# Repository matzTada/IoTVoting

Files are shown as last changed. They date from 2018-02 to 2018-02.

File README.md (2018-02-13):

# IoTVoting

IoT教育向け投票システム  
ボタンを押した回数に対応してフルカラーLEDの色が変わる．複数ノードから無線通信で色情報を一か所に収集し，視覚化する．色のコントロールを遠隔で行うことも可能．

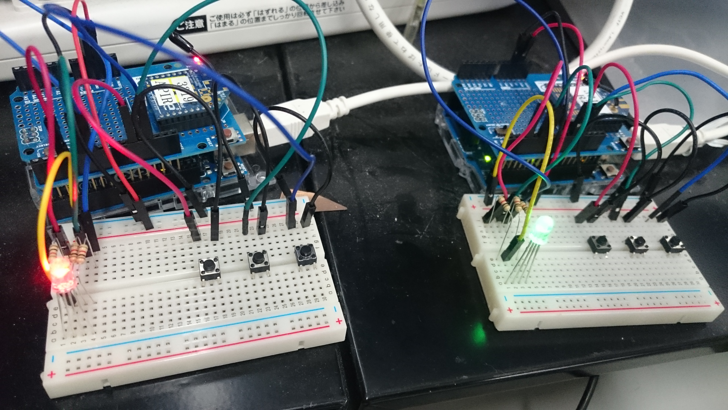
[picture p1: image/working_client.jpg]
working_client

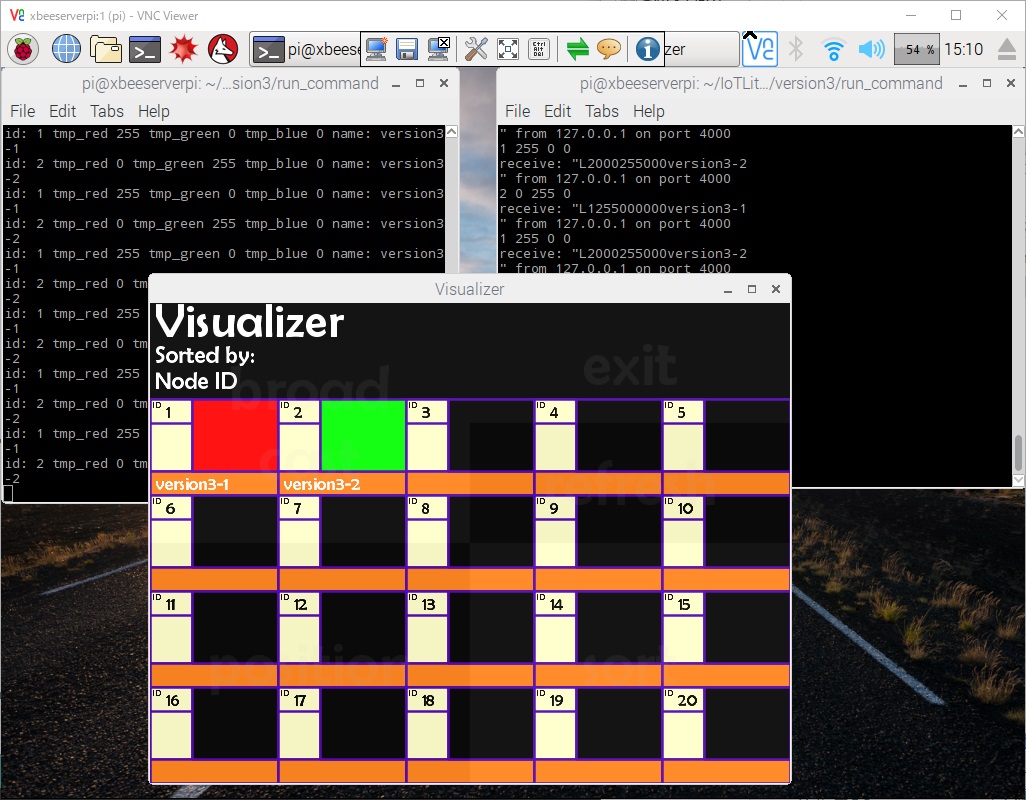
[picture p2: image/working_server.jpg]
working_server


[IoTLiteracyEdu](https://github.com/matzTada/IoTLiteracyEdu)プロジェクトの後継版  
技術面での変更点

* データベースの廃止→プログラム間のソケット通信に変更
* XBee通信のちょっとした改良(WandWoFulも参考に)
* プログラムの簡略化

## やっていること，できること

* クライアント側
	* R,G,Bに対応して一つずつボタンがある
	* ボタンを押した回数に対応してフルカラーLEDの色が変わる
	* LEDの状態（色）を定期的にサーバに送信
* サーバ側
	* クライアント側からのデータを視覚化
	* クライアント側に色情報を一斉送信（コントロールできる）

## 考えられる遊び方

* 一番多い色を集計し，すべてのノードをその色に塗り替える
* 表現できる色それぞれに選択肢を対応付けて投票する
	* 例えば，「お題：好きな果物，選択肢：赤＝リンゴ，緑＝メロン，青＝それ以外」　など
	* 「好きな教科」「好きなスポーツ」「好きな言語」等なんでもできる．
* まわりの人と色を合わせるには
	* プロトコルの考えにもつながる
	* 相談あり，相談なし，事前にルールを決める，隣の人の色しかわからない等の応用が利く
* てかまあ，情報教育としてじゃなくて，単になんかしらの投票するときとか面白いかもね．

## 主要登場人物とつながり

* クライアント側
	* Arduino
	* XBee (ZigBee)
	* Full Color LED (3色LED)
	* Tact switch
* サーバー側
	* Raspberry Pi (別にラズパイじゃなくても可)
	* XBee (ZigBee)
	* Processing
	* Python

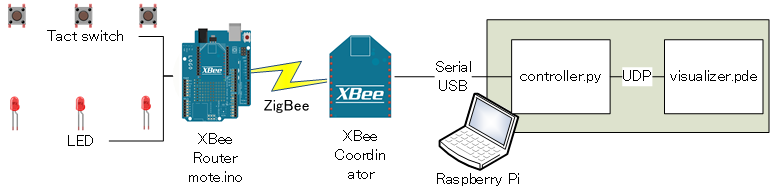
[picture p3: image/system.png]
system
  

## クライアントノード配線

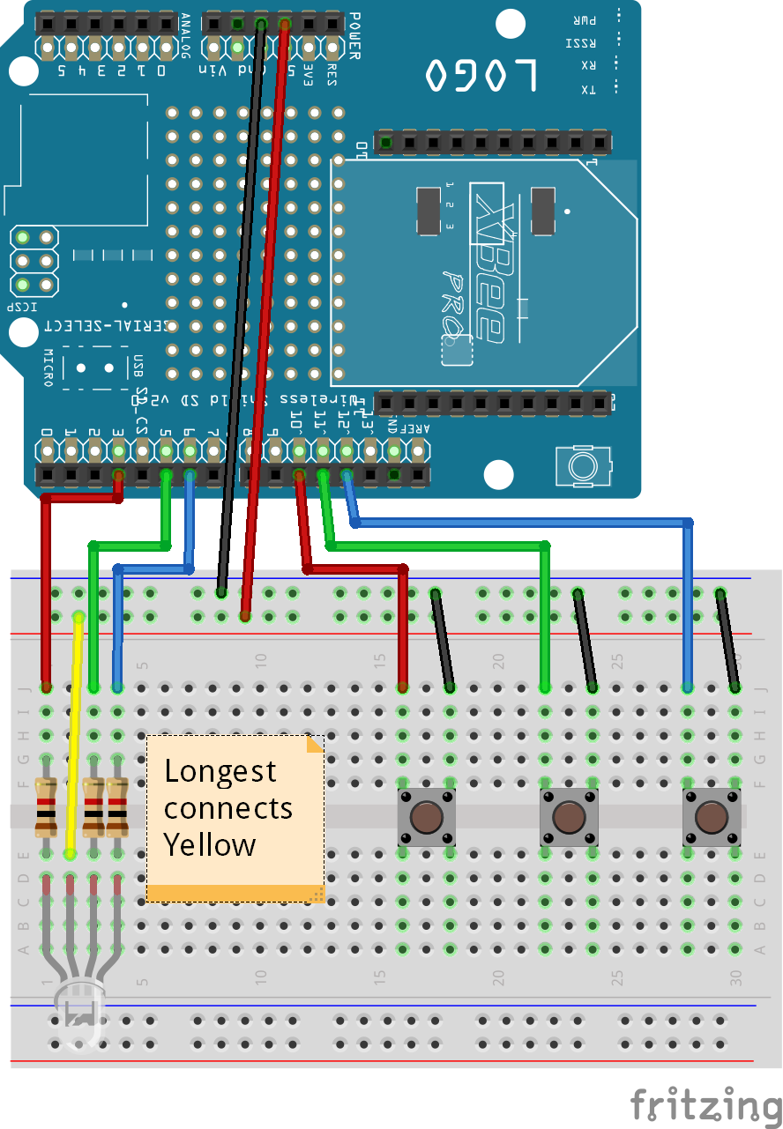
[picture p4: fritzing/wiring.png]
wiring


## 授業に入る前の準備手順

1. Arduinoのノードを配線する
2. ```arduino/mode```以下のプログラムを理解する
3. クライアント側ノードをテストする
	3. ```arduino/mode/mote.inoと同じディレクトリのファイル```をArduino IDEで開き，これをArduinoに焼く
	1. LEDが光るか
	2. ボタンを押してカウントができているか
	3. ボタンを押したらLEDの色が変わるか
2. XBeeの設定
	1. XBeeにテプラなどでIDを貼り、アドレスとの対応をメモっておく
	2. X-CTUのインストール
	3. X-CTUでFirmwareの設定
		1. Coordinatorはネットワークに一つ，他は全部Router
		2. PAN IDをそろえる（そろってないと当たり前のように通信できない）
		3. API enable = 2にする．ライブラリの都合上結構な大事
4. XBeeの通信テスト
	1. 送信はArduinoプログラム（送信先アドレスをCoordinatorに合わせる）
	2. 受信（CoordinatorをPCなりRasPiなりに接続）
		1. X-CTUの端末でみてみる
		3. Pythonで受けてみる（Serialライブラリを使う）
3. ソケット通信テスト
	1. PythonでUDP通信してみる
	2. ProcessingでUDP通信してみる
	3. PythonとProcessingの間でUDP通信してみる
3. サーバ側Controllerのテスト
	1. ```python/controller.py```を試す
	1. クライアント側からデータを受信できているか
	2. 受信したデータをUDPで送信できているか
3. サーバ側Visualizerのテスト
	1. ```processing/visualizer/visualizer.pdeと同じディレクトリのファイル```をProcessing IDEで開く
	2. UDPで受信できているか
	3. 視覚化できているか
4. クライアント側をコントロールできているか試す

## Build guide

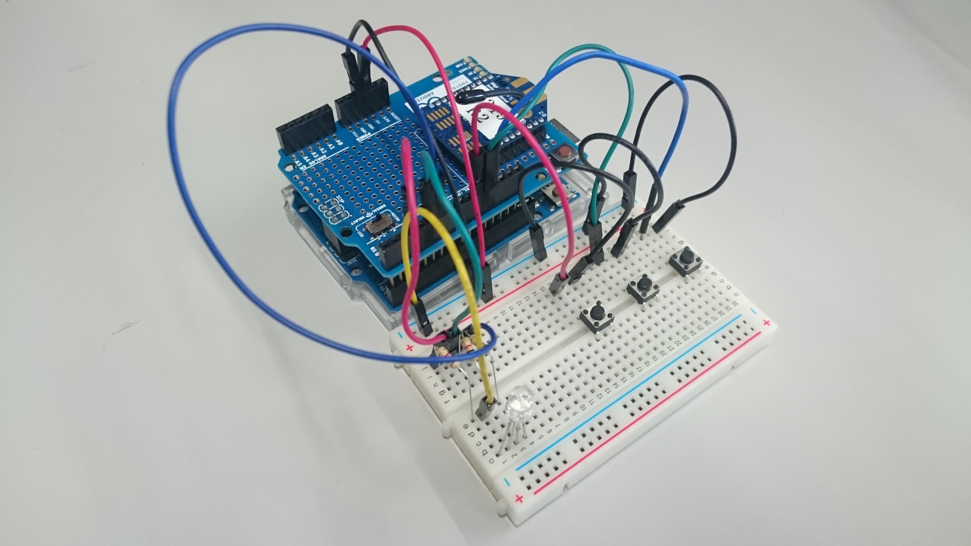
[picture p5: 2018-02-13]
image/wiring_client.jpg

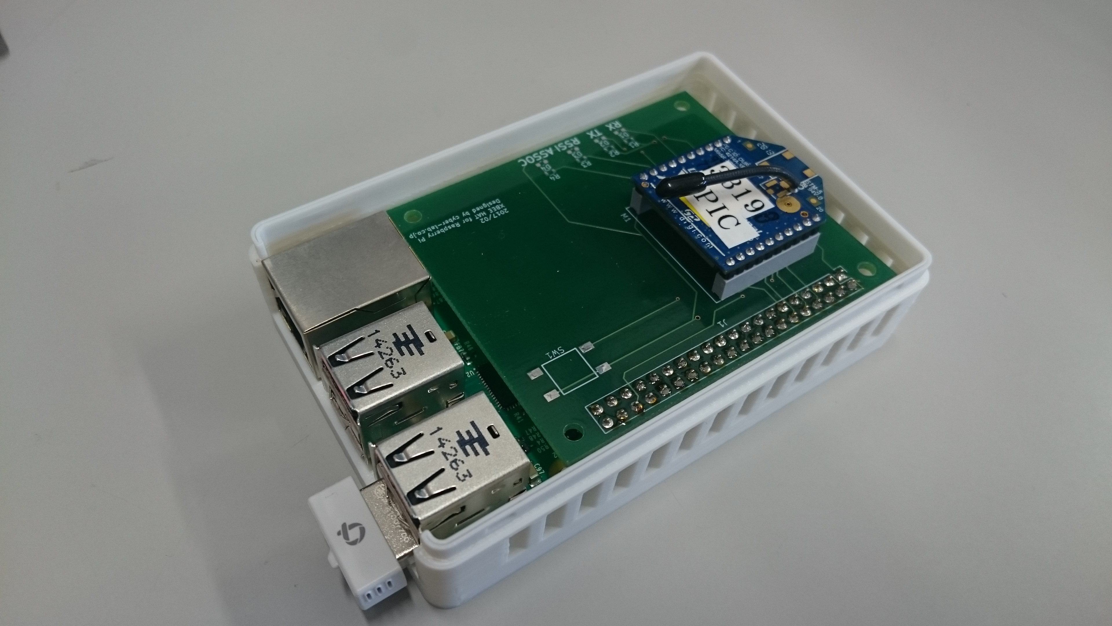
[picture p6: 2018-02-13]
image/wiring_server.jpg

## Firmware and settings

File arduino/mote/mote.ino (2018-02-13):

// mote.ino
// Program for Arduino version3
// Keio University Westlab 2017.12
// Author: Tada Matz

//<==== Please change according to an instruction
String MOTENAME = "version3-2"; //recommended to be between 1 ~ 10
int MOTEID = 2; //should be from 1 ~ 20
//====>Please change according to an instruction

#define LED_RED_PIN 3
#define LED_GREEN_PIN 5
#define LED_BLUE_PIN 6

#define BUTTON_RED_PIN 10
#define BUTTON_GREEN_PIN 11
#define BUTTON_BLUE_PIN 12

int oldR = 0, oldG = 0, oldB = 0; //old button values for click detection
#define CNT_MAX 2
int cntR = 0, cntG = 0, cntB = 0;
int colorR = 0, colorG = 0, colorB = 0;

#include "source.h"
MyXBee myxbee;
unsigned long pastMillis = millis();
#define SEND_INTERVAL 1000
#define LED_HEADER 'L'
#define ID_PACKET_OFFSET '0'

int clickDetection(int _pin, int * _oldstate) { //click detection
  int buttonClicked = 0;
  int newButtonState = digitalRead(_pin);
  if (*_oldstate == HIGH && newButtonState == LOW) buttonClicked = 1; //button pressed. CAUTION pull up
  *_oldstate = newButtonState;
  return buttonClicked;
}

void setup() {
  Serial.begin(9600);
  myxbee.init(Serial);

  pinMode(LED_RED_PIN, OUTPUT);
  pinMode(LED_GREEN_PIN, OUTPUT);
  pinMode(LED_BLUE_PIN, OUTPUT);

  pinMode(BUTTON_RED_PIN, INPUT_PULLUP);
  pinMode(BUTTON_GREEN_PIN, INPUT_PULLUP);
  pinMode(BUTTON_BLUE_PIN, INPUT_PULLUP);
}

void loop() {
  if (clickDetection(BUTTON_RED_PIN, &oldR)) {
    cntR = cntR + 1;
    if (cntR >= CNT_MAX) cntR = 0;
    colorR = (int)map(cntR, 0, CNT_MAX - 1, 0, 255);
  }

  if (clickDetection(BUTTON_GREEN_PIN, &oldG)) {
    cntG = cntG + 1;
    if (cntG >= CNT_MAX) cntG = 0;
    colorG = (int)map(cntG, 0, CNT_MAX - 1, 0, 255);
  }
  if (clickDetection(BUTTON_BLUE_PIN, &oldB)) {
    cntB = cntB + 1;
    if (cntB >= CNT_MAX) cntB = 0;
    colorB = (int)map(cntB, 0, CNT_MAX - 1, 0, 255);
  }

  // receiving
  String receiveStr = myxbee.receiveXBeeData();
  if (receiveStr.length() > 0 && receiveStr.charAt(0) == LED_HEADER) { // packet should be "L1RRRGGGBBB\n"
    // int senderid = int(receiveStr.charAt(1) - ID_PACKET_OFFSET);
    colorR = receiveStr.substring(2, 5).toInt();
    colorG = receiveStr.substring(5, 8).toInt();
    colorB = receiveStr.substring(8, 11).toInt();
  }

  // sending periodically
  if (millis() - pastMillis > SEND_INTERVAL) {
    pastMillis = millis();

    char tempsenddata[1 + 1 + 9];
    sprintf(tempsenddata, "%c%c%03d%03d%03d",
            LED_HEADER,
            MOTEID + int(ID_PACKET_OFFSET),
            colorR, colorG, colorB);
    String data = tempsenddata + MOTENAME + "\n"; // packet should be "L1RRRGGGBBB"
    myxbee.sendXBeeData(data);
  }

  // put on LED
  analogWrite(LED_RED_PIN, 255 - colorR);
  analogWrite(LED_GREEN_PIN, 255 - colorG);
  analogWrite(LED_BLUE_PIN, 255 - colorB);
}

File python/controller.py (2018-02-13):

import serial
import time
import array
import sys

import socket

def readSerial(ser): #can process the Escape mode API = 2
    var = ord(ser.read())
    if(var == 0x7D):
        var = ord(ser.read()) ^ 0x20
    return var

def chrWithEscape(value):
    var = chr(value)
    if(value == 0x7E or value == 0x7D or value == 0x11 or value == 0x13):
        var = chr(0x7D) + chr(value ^ 0x20)
    return var

def makeZigBeeTransmitRequestPacket(dst64addrH, dst64addrL, dst16addr, payLoad): #Frame type = 0x10 packet sender
    length = 1 + 1 + 8 + 2 + 1 + 1 + len(payLoad)

    frameData = chr(0x10) #frameType
    frameData += chr(0x01) #frameID

    sp8 = chr(dst64addrH % 256) #dst64addr High
    dst64addrH = dst64addrH / 256
    sp7 = chr(dst64addrH % 256)
    dst64addrH = dst64addrH / 256
    sp6 = chr(dst64addrH % 256) 
    dst64addrH = dst64addrH / 256
    sp5 = chr(dst64addrH % 256)

    sp12 = chr(dst64addrL % 256) #dst64addr Low
    dst64addrL = dst64addrL / 256
    sp11 = chr(dst64addrL % 256)
    dst64addrL = dst64addrL / 256
    sp10 = chr(dst64addrL % 256)
    dst64addrL = dst64addrL / 256
    sp9 = chr(dst64addrL % 256)

    frameData += sp5 + sp6 + sp7 + sp8 + sp9 + sp10 + sp11 + sp12

    frameData += chr((dst16addr / 256) % 256) #dst16addr
    frameData += chr(dst16addr % 256)

    frameData += chr(0x00) #Broadcast radius
    frameData += chr(0x00) #options

    frameData += payLoad #data payload

    checksum = 0 #checksum calculation
    for i in frameData:
        checksum += ord(i)
    checksum = 0xFF - ord(chr(checksum % 256))
    # print "checksum:", checksum

    tempPacket = chr((length / 256) % 256) + chr(length % 256) + frameData + chr(checksum)

    sendPacket = chr(0x7E)
    for i in tempPacket:
        sendPacket += chrWithEscape(ord(i))

    print "===> send", length, "bytes data. Data: ", payLoad
    # print "     hex:",
    # for i in sendPacket:
    #     print hex(ord(i)),
    # print ""

    return sendPacket

if __name__ == "__main__":
  LED_HEADER = 'L'
  ID_PACKET_OFFSET = '0'

  SRC_PORT = 4000
  DST_HOST = "localhost"
  DST_PORT = 4001

  #<=== Serial port initialization
  print "serial port initialization start"
  port = '/dev/ttyAMA0' #XBee Explorer via USB that is for raspberry pi
  #port = 'COM44' #XBee Explorer
  serialPort = serial.Serial(port, 9600, timeout = 1)
  print port + " is opend"
  time.sleep(2) #wait for establishing stable serial connection
  print "serial port initialization end"
  #===> Serial port initialization

  #<=== udp server
  sock = socket.socket(socket.AF_INET, socket.SOCK_DGRAM)
  sock.bind(("", SRC_PORT))
  sock.setblocking(False)
  bufsize = 4096
  #===> udp server


  while True:
    try:
      #<=== packet receiving
      if serialPort.inWaiting() > 0: #if something is in serial port
        var = readSerial(serialPort)
        if(var == 0x7E): #and if this is the XBee packet

          frameData = []
          frameData.append(var)

          frameData.append(readSerial(serialPort))
          frameData.append(readSerial(serialPort))
          frameLength = frameData[1] * 256 + frameData[2]
          # print "<=== received hex:", hex(var), hex(frameData[1]), hex(frameData[2]),

          counter = 0
          checksumsum = 0
          while counter < frameLength + 1:
            var = readSerial(serialPort)
            frameData.append(var)
            checksumsum += var
            # print hex(var),
            counter += 1
            # print ""

          #print "frameLength:", frameLength,
          #print "frameData:", frameData
          #print "checksumsum:", hex(checksumsum)

          frameType = frameData[3]
          # print "frameType:", hex(frameType)

          if(frameType == 0x90): #ZigBee Receive Packet Response
            #print "<=== ZigBee Receive Packet: ",
            src64addrH = 0
            for i in range(0,4):
              src64addrH += frameData[i + 4] * pow(256,(3 - i))
              src64addrL = 0
            for i in range(0,4):
              src64addrL += frameData[i + 8] * pow(256,(3 - i))
              src16addr = frameData[12] * 256 + frameData[13]
            receiveOptions = frameData[14]
            receiveData = ""
            for i in range(15, frameLength + 3):
              receiveData += chr(frameData[i])
            # print "str(bytearray(receiveData)):", str(bytearray(receiveData))

            payloadType = receiveData[0]
            # print "payloadType: ", str(hex(payloadType)), "chr(payloadType): ", str(chr(payloadType))
            if payloadType == LED_HEADER and len(receiveData) >= 11:
              tmp_id = int(ord(receiveData[1]) - ord(ID_PACKET_OFFSET))
              tmp_red = int(receiveData[2:5]) 
              tmp_green = int(receiveData[5:8]) 
              tmp_blue = int(receiveData[8:11]) 
              tmp_name = receiveData[11:len(receiveData)]
              
              # print "len:", frameLength, "data:", str(bytearray(receiveData)).strip()
              print  "id:", tmp_id, "tmp_red", tmp_red, "tmp_green", tmp_green, "tmp_blue", tmp_blue, "name:", tmp_name.strip()
              sock.sendto(receiveData, (DST_HOST, DST_PORT))
        #===> packet receiving

      #<=== udp processing
      data, address = sock.recvfrom(bufsize)
      print "udp receive:", data, "address:", address

      if len(data) >= 11 and data[0] == LED_HEADER:
        #<=== broadcast packet sending
        print "triger to send broadcast packet!!"
        temp = makeZigBeeTransmitRequestPacket(0x00000000, 0x0000FFFF, 0xFFFE, data)
        serialPort.write(temp)
        time.sleep(1)

        #===> broadcast packet sending
      #===> udp processing

    except socket.error:
      pass
    except:
      print "finish program"
      sock.close()
      serialPort.close()
      print port + " is closed."
      exit()
 
